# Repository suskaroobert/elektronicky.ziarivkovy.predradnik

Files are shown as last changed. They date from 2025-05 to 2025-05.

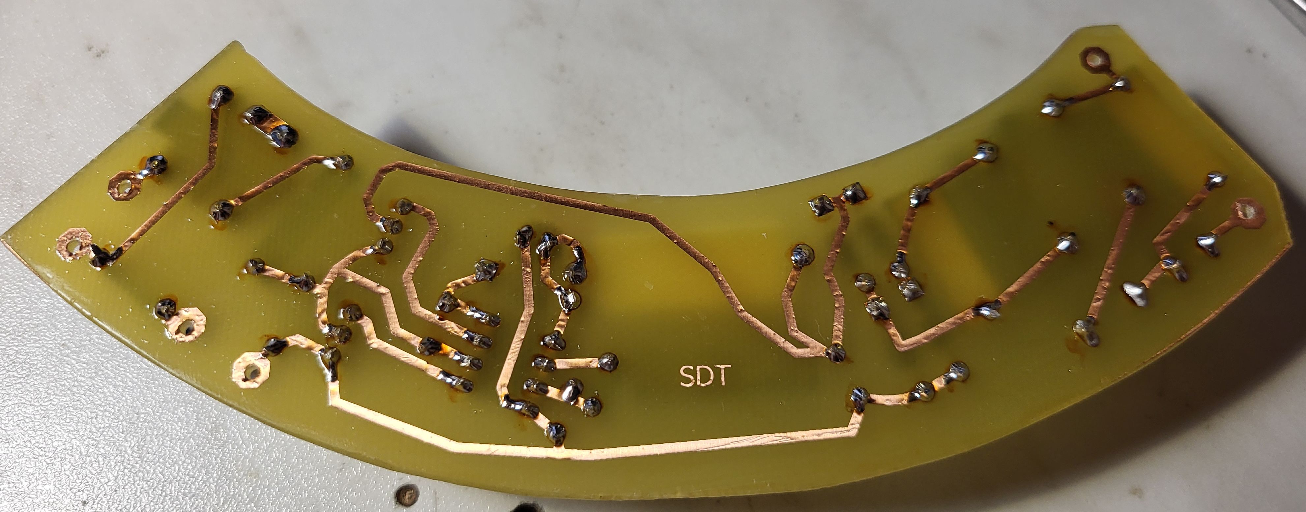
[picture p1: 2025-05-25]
media/20250525_101909.jpg

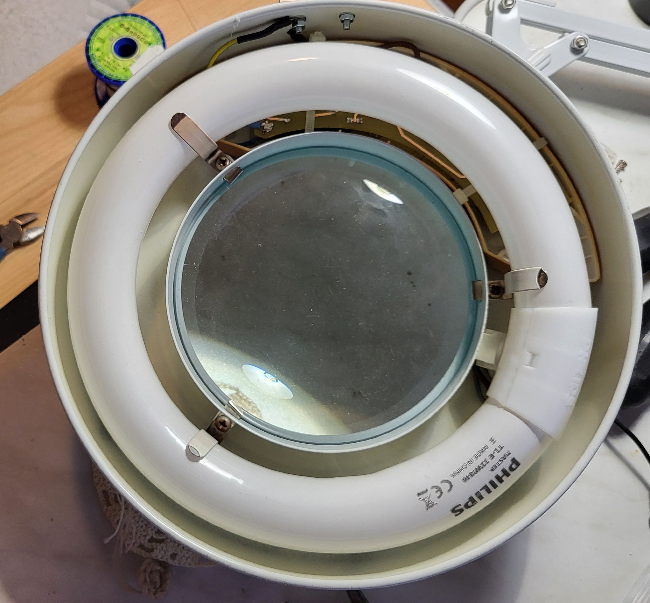
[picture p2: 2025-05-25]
media/20250525_131609.jpg

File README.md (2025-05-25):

# Oprava Pro'sKit Magnifier Lamp Neon

---

Potom čo mi odišla do večných lovísk moja neónka, som sa rozhodol, že ju zreparujem. Inšpiráciu som najprv hľadal na konferencii [Hw-list][hwlist] kde ma jeden príspevok naviedol na slovo predradník. Síce som chvíľku uvažoval o tom, že žiarivku nahradím LED diódami, ale toto riešenie som ihneď zavrhol, keď som objavil na stránke [https://danyk.cz/][danyk]

[Elektronický zářivkový předřadník 8 - 144W][danykpredradnikcz]

Jeho stavba skončila úspešne, za čo som autorovi veľmi vďačný.

Moje riešenie spočíva v tom, že som schému prekreslil do programu EAGLE a navrhol na DPS, ktorý vojde do otvoru pre pôvodnú elektroniku lampy.

## Poznámky ku stavbe

Rezistor R2 je počas prevádzky veľmi horúci. Vytiahol som ho preto mimo priestor lampy, do malej krabičky z hliníkového plechu. Z vrchu a od spodu sú v krabičke navŕtané otvory pre lepšie chladenie rezistoru.

Ďalej, pôvodný prívodný kábel bol len dvojžilový, tak som ho vymenil za trojžilový a kryt svietidla a krabičku s rezistorom som uzemnil.

## ENG version

After my fluorescent tubes went to the eternal hunting grounds, I decided to repair it. I first looked for inspiration on the [Hw-list][hwlist] mailing list, where a post led me to the word ballast. Although I briefly considered replacing the fluorescent bulb with LEDs, I immediately dismissed this solution when I discovered on the site [https://danyk.cz/][danyk]

[Electronic ballast for fluorescent tubes 8 - 144W][danykpredradnikeng]

Its construction ended successfully, for which I am very grateful to the author.

My solution was to redraw the schematic in EAGLE and design a PCB that fits into the hole for the original lamp electronics.

## Notes on the building

Resistor R2 is very hot during operation. I therefore pulled it out of the lamp compartment, into a small box made of aluminum sheet. There are holes drilled in the box from the top and bottom for better cooling of the resistor.

Next, the original supply cable was only two-wire, so I replaced it with a three-wire one and grounded the lamp cover and the resistor box.

[hwlist]: https://list.hw.cz/mailman/listinfo/hw-list
[danyk]: https://danyk.cz/
[danykpredradnikcz]: https://danyk.cz/zarivk_p.html
[danykpredradnikeng]: https://danyk.cz/zarivk_p_en.html

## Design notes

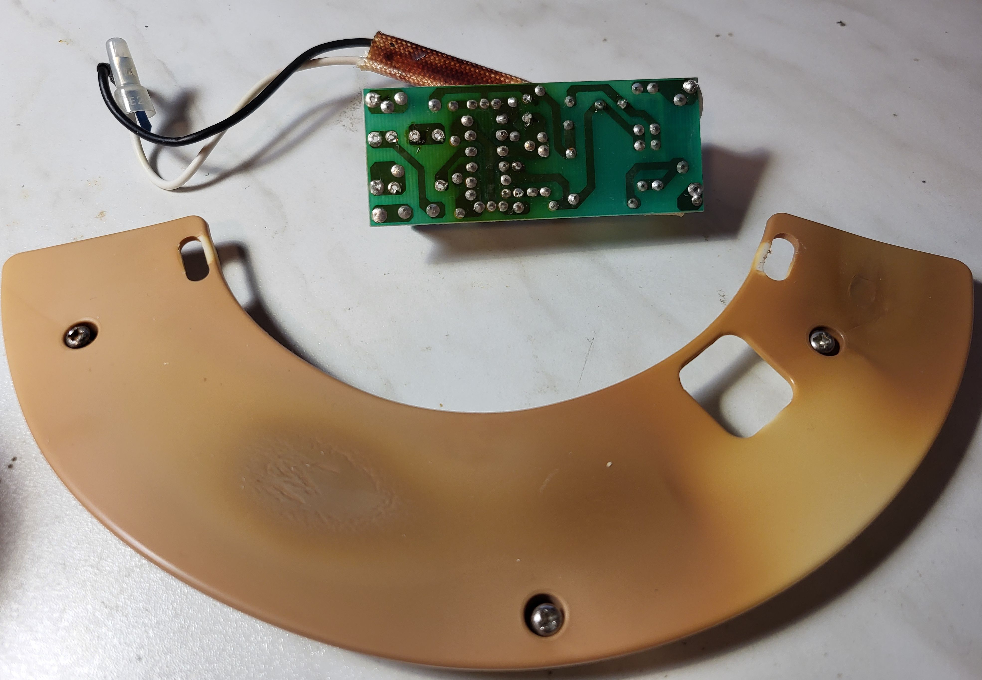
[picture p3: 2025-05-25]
media/orig_pw_source.2.jpg

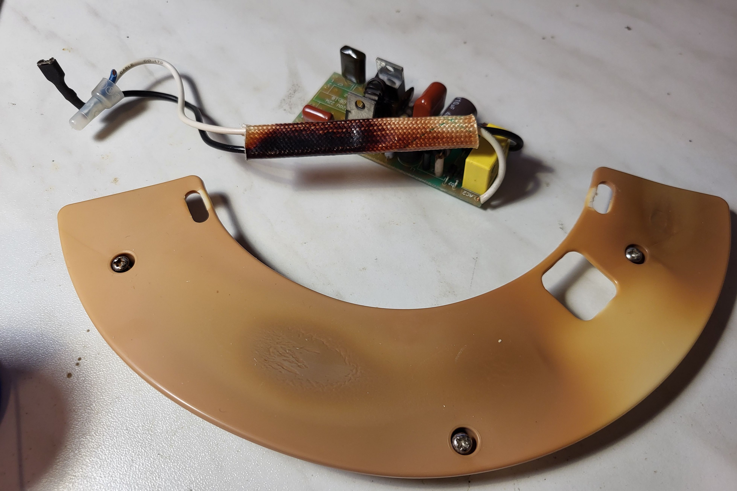
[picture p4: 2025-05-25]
media/orig_pw_source.1.jpg

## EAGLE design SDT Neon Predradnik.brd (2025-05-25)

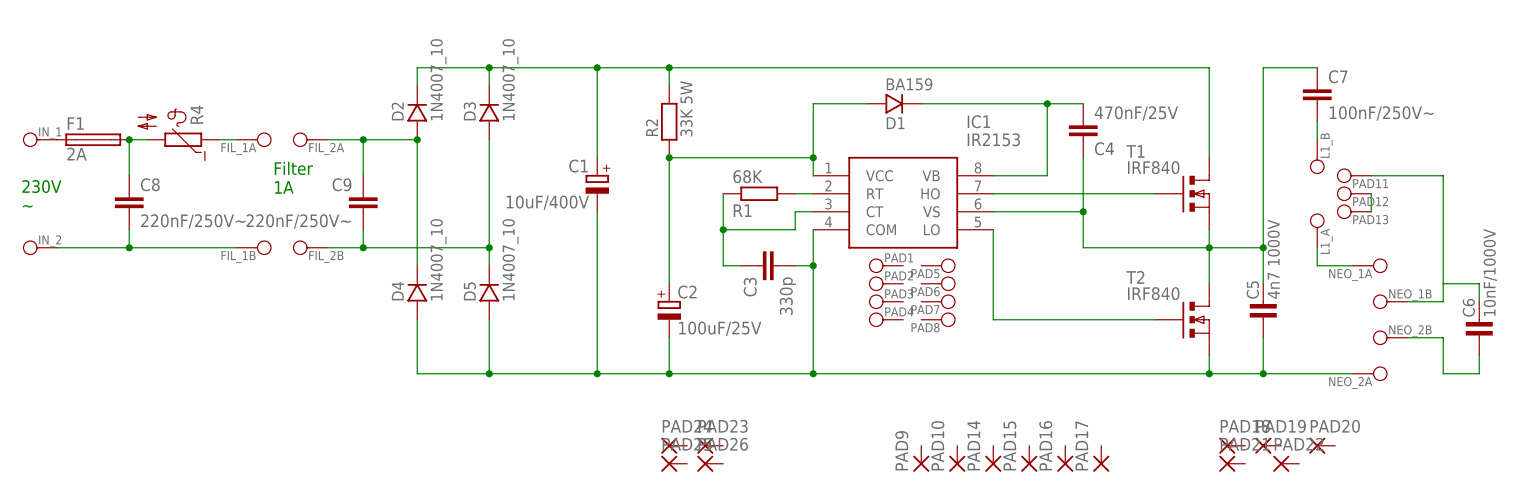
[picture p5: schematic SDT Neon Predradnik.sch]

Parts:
C1: 10uF/400V; ELEKTROLITICKY_RM5-10
C2: 100uF/25V; ELEKTROLITICKY_RM2,5-6,3
C3: 330p; KERAMICKY_RM5
C4: 470nF/25V; FOLIOVY_RM5/3,5-7,2
C5: 4n7 1000V; C-7,5
C6: 10nF/1000V; C-10
C7: 100nF/250V~; FOLIOVY_RM15/5-18
C8, C9: 220nF/250V~; FOLIOVY_RM15/5-18
D1: BA159; D-10
D2, D3, D4, D5: 1N4007_10; D-10
F1: 2A; TE5
FIL_1A, FIL_1B, FIL_2A, FIL_2B: PAD_1---
IC1: IR2153; DIP762W56P254L988H533Q8N
IN_1, IN_2: IN_~_1; PAD_1---
L1_A, L1_B: PAD_1---
NEO_1A, NEO_1B, NEO_2A, NEO_2B: PAD_1---
PAD1, PAD2, PAD3, PAD4, PAD5, PAD6, PAD7, PAD8, PAD11, PAD12, PAD13: PAD_1---
PAD9, PAD10, PAD14, PAD15, PAD16, PAD17: 3,81/1,3
PAD18, PAD19, PAD20, PAD21, PAD22, PAD23, PAD24, PAD25, PAD26: 2,54/1,1
R1: 68K; 0204/5
R2: 33K 5W; R-_5W
R4: NTC644C; N644C
T1, T2: IRF840; TO-220S

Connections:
unnamed: F1.1, IN_1.1
unnamed: C8.P$1 (1), F1.2, R4.2
unnamed: C8.P$2 (2), FIL_1B.1, IN_2.1
unnamed: FIL_1A.1, R4.1
unnamed: C9.P$1 (1), D2.A, D4.K, FIL_2A.1
unnamed: IC1.7 (HO), T1.1 (G)
unnamed: C1.P$2 (+), D2.K, D3.K, R2.2, T1.2 (D)
unnamed: C6.2, NEO_1B.1, PAD11.1
unnamed: IC1.5 (LO), T2.1 (G)
unnamed: C4.P$2 (2), D1.K, IC1.8 (VB)
unnamed: IC1.2 (RT), R1.2
unnamed: C3.P$1 (1), IC1.3 (CT), R1.1
unnamed: C4.P$1 (1), C5.2, C7.P$1 (1), IC1.6 (VS), T1.3 (S), T2.2 (D)
unnamed: C1.P$1 (-), C2.P$1 (-), C3.P$2 (2), C5.1, D4.A, D5.A, IC1.4 (COM), NEO_2A.1, T2.3 (S)
unnamed: C2.P$2 (+), D1.A, IC1.1 (VCC), R2.1
unnamed: C7.P$2 (2), L1_B.1
unnamed: C6.1, NEO_2B.1
unnamed: L1_A.1, NEO_1A.1
unnamed: C9.P$2 (2), D3.A, D5.K, FIL_2B.1
unnamed: PAD12.1, PAD13.1

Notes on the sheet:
230V ~
Filter 1A

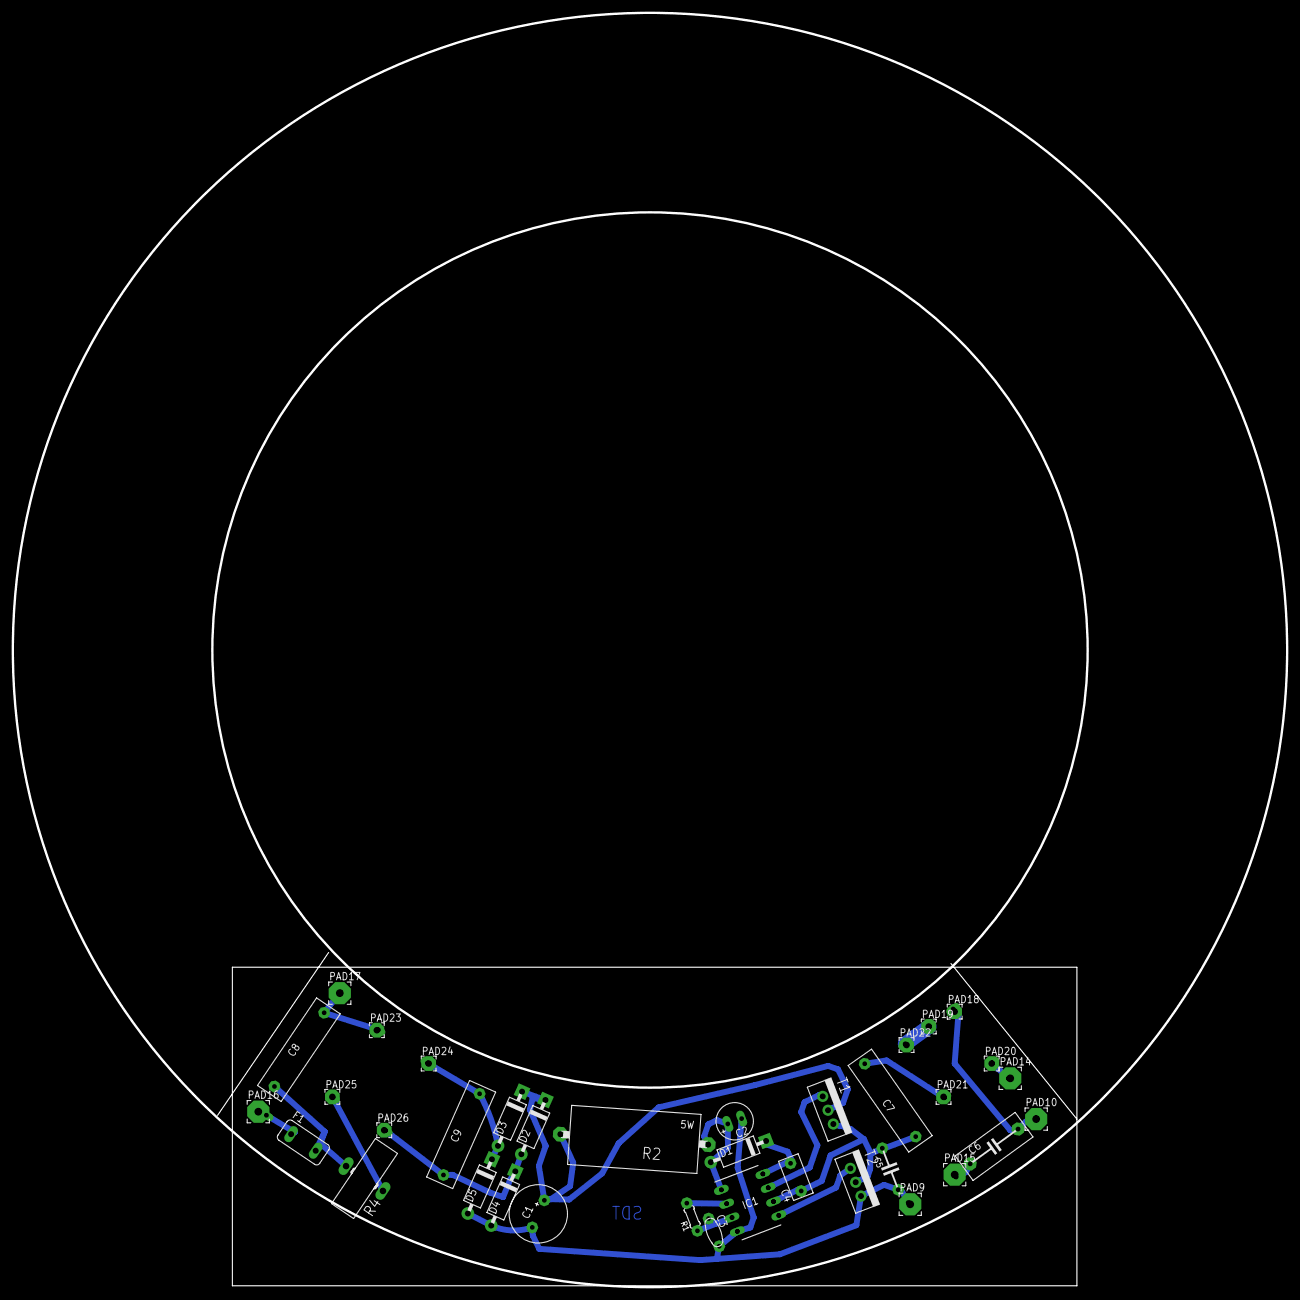
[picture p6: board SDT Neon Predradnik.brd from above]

Board: 2 copper layers, 218.5 x 218.5 mm, 59 parts (0 on the bottom side), 20 nets.

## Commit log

2025-05-23 - prvy
    [SDT Neon Predradnik.brd, SDT Neon Predradnik.sch]
2025-05-23 - zmena gridu
    [SDT Neon Predradnik.brd, SDT Neon Predradnik.sch]
2025-05-25 - final
    [SDT Neon Predradnik.brd, SDT Neon Predradnik.sch]

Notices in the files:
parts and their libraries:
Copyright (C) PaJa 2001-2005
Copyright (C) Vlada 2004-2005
